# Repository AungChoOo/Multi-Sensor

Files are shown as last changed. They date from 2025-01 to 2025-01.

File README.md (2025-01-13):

<h1>Multi-Sensor</h1>

<h2>13 in 1 multi-sensor breadboard compatible module.</h2>

- IMU sensor([BMI088](https://www.bosch-sensortec.com/products/motion-sensors/imus/bmi088/))
- Magnetometer([BMM150](https://www.bosch-sensortec.com/products/motion-sensors/magnetometers/bmm150/))
- Gas Sensors([BME680](https://www.bosch-sensortec.com/products/environmental-sensors/gas-sensors/bme680/))

<h2>Rendered Image</h2>
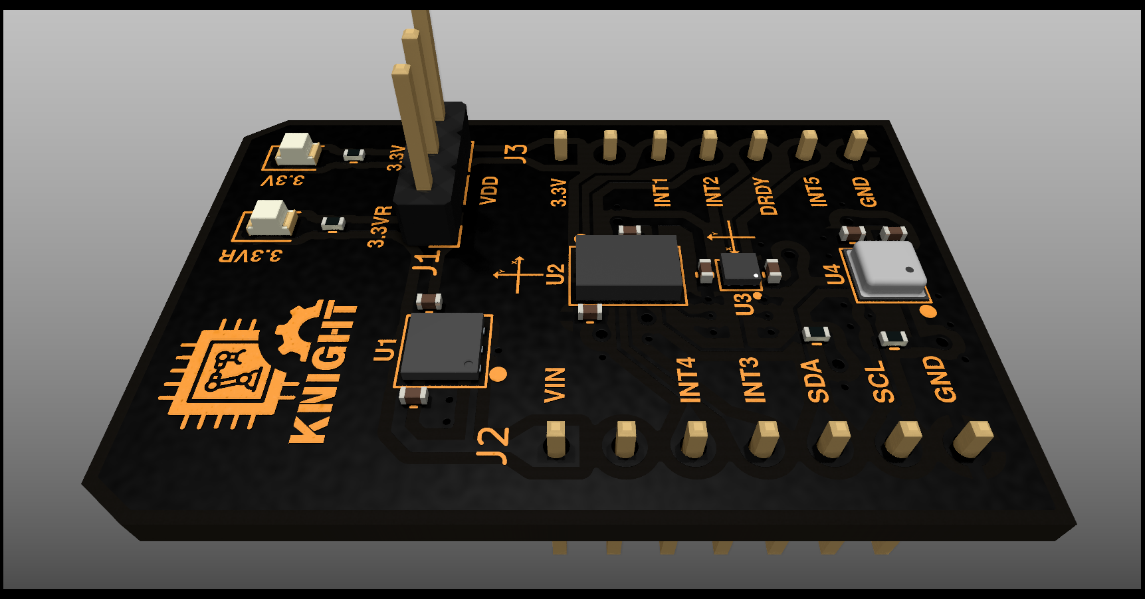
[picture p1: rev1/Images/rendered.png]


<h2>Front and Back Side</h2>
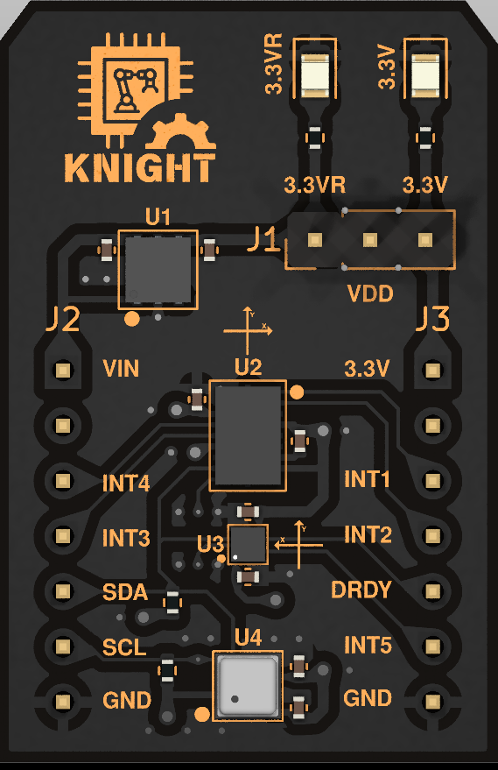
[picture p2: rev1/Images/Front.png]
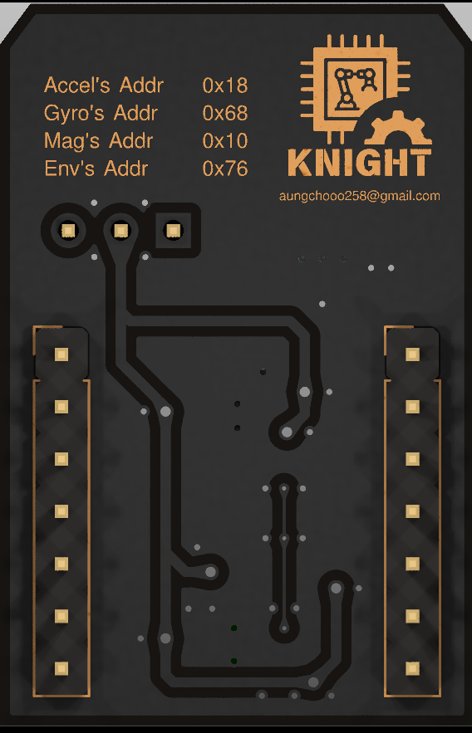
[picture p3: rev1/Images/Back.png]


## License
Resources of this repository are distributed under MIT License. 
See [LICENSE](./LICENSE).

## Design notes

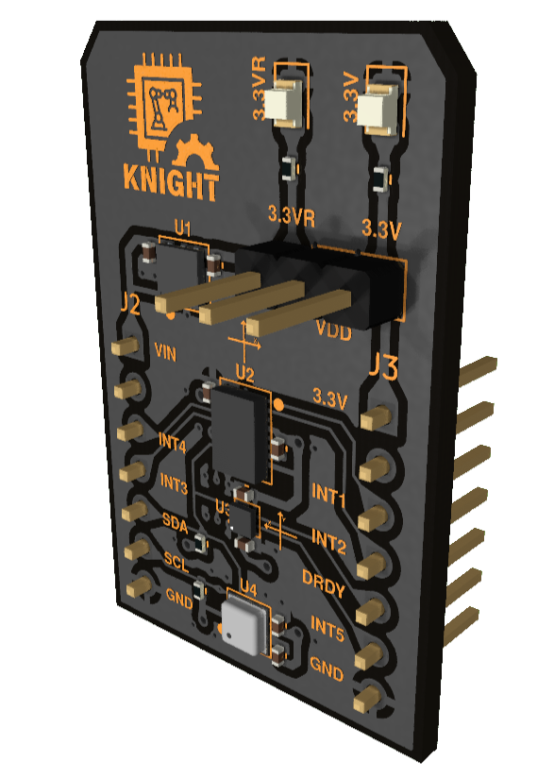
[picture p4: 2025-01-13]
rev1/Images/background_front.png

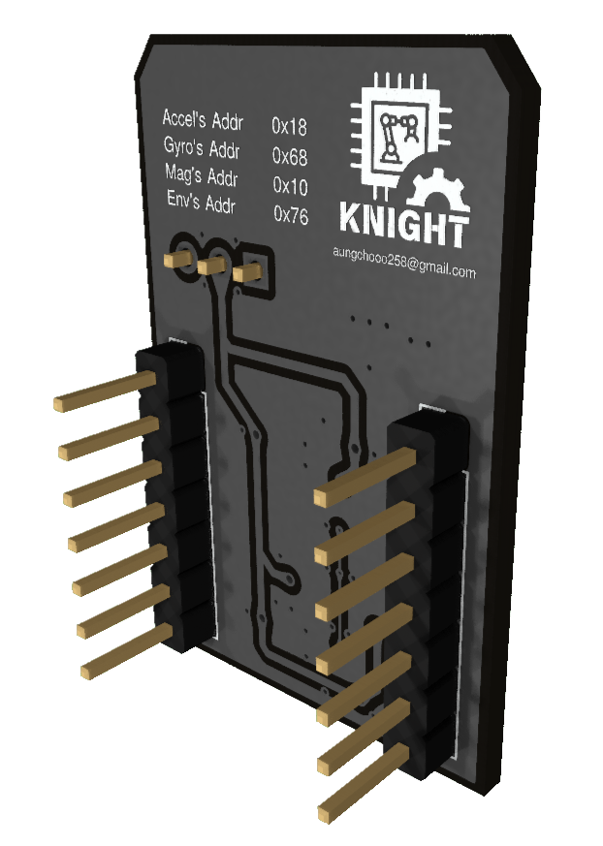
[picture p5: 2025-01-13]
rev1/Images/background_back.png

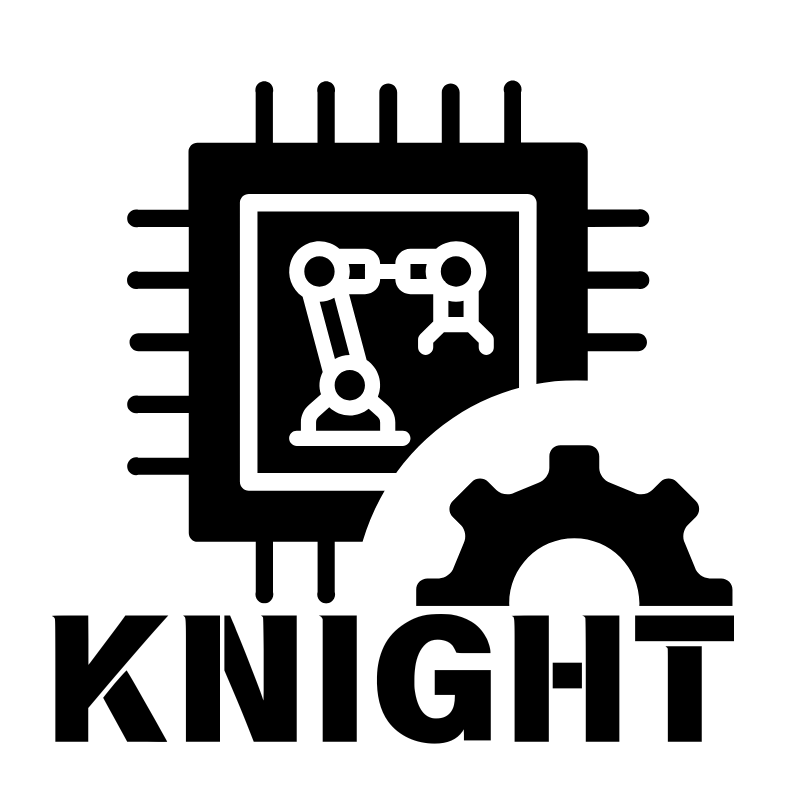
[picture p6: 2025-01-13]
rev1/Images/Knight.png

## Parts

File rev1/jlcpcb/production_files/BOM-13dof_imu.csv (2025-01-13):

Comment | Designator | Footprint | LCSC | Quantity
1kR | R1,R2 | R_0402_1005Metric | C11702 | 2
BME680 | U4 | BME680 | C125972 | 1
100nF | C3,C4,C5,C6,C7,C8 | C_0402_1005Metric | C1525 | 6
BMM150 | U3 | BMM150 | C171681 | 1
NCP708 | U1 | NCP708 | C183178 | 1
BMI088 | U2 | BMI088 | C194919 | 1
LED | D1,D2 | LED_0805_2012 | C2297 | 2
4u7F | C1,C2 | C_0402_1005Metric | C23733 | 2
4k7R | R4 | R_0402_1005Metric | C25900 | 1
Vbus | J1 | PinHeader_1x03_P2.54mm_Vertical | C6332196 | 1
Right | J3 | PinHeader_1x07_P2.54mm_Vertical |  | 1
Left | J2 | PinHeader_1x07_P2.54mm_Vertical |  | 1

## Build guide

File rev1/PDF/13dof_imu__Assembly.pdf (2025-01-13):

# Multi Sensor

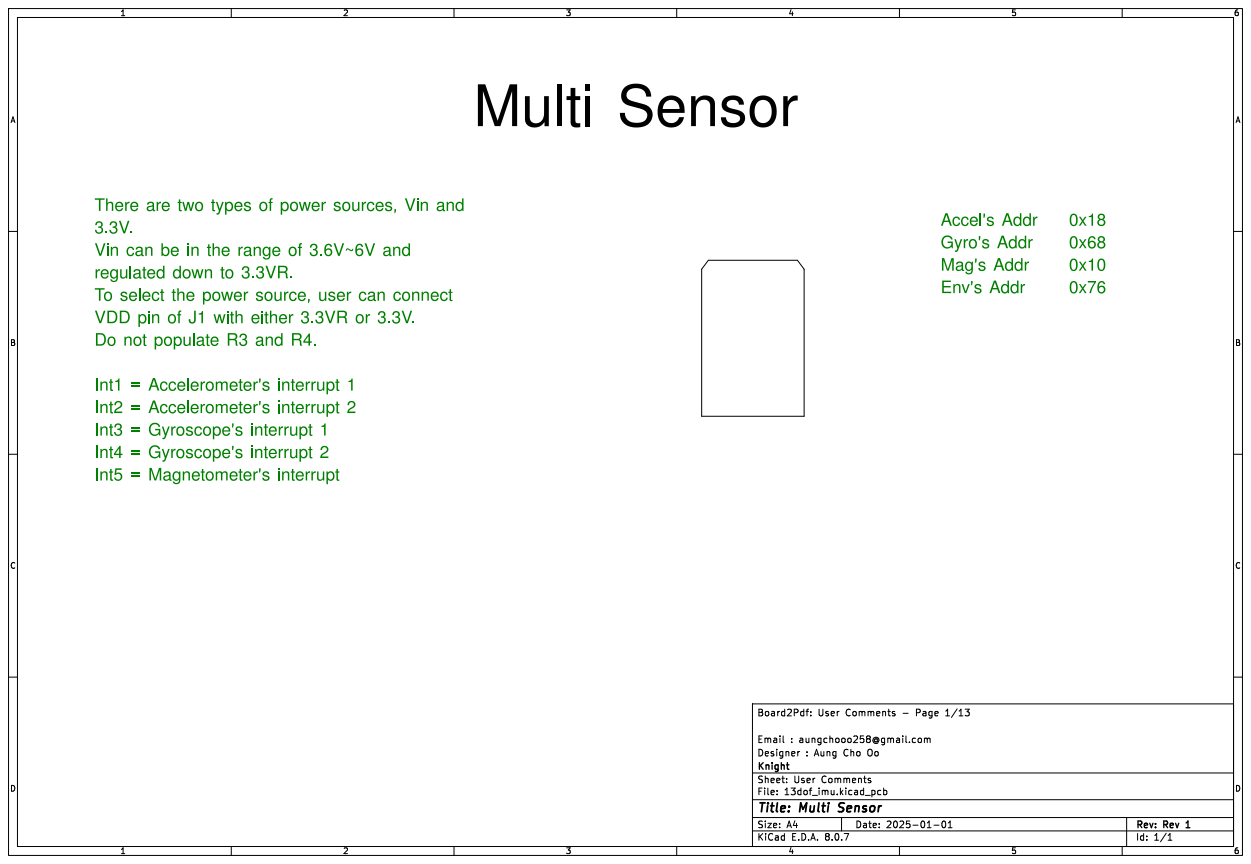
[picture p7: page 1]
Accel'sAddr 0x18 Gyro'sAddr 0x68 Mag's Addr 0x10 Env's Addr 0x76; Int1 = Accelerometer'sinterrupt1 Int2 = Accelerometer'sinterrupt2 Int3 = Gyroscope'sinterrupt1 Int4 = Gyroscope'sinterrupt2 Int5 = Magnetometer'sinterrupt; D Date: 2025-01-01 KiCad; E.D.A. 8.0.7 Size: A4; Rev:; Rev; Board2Pdf:; User Comments -; Page

There are two types of power sources,Vin and
Vin can be in the range of 3.6V~6Vand
regulateddown to 3.3VR.
To select the power source,user can connect
VDD pin of J1 with either 3.3VR or 3.3V.
Do not populateR3 and R4.

Designer : Aung Cho Oo Email : aungchooo258@gmail.com

Id: 1/1 Title: Multi Sensor File: 13dof_imu.kicad_pcb Sheet: User Comments Knight

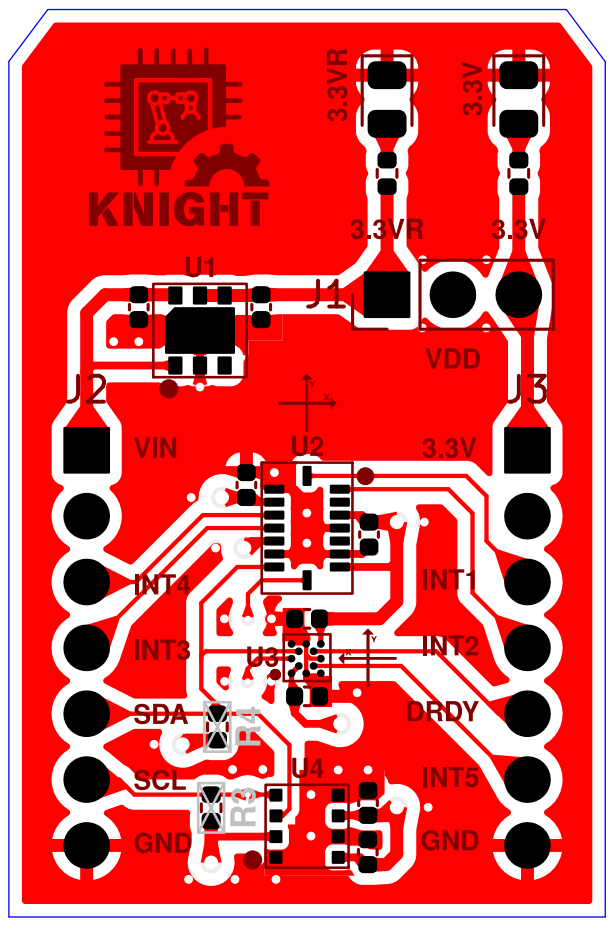
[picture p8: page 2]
DRDY; SCL; INT5 SDA; INT1; INT2 GND; VDD; VIN; GND; INT3; INT4; D Date: 2025-01-01 KiCad; E.D.A. 8.0.7 Size: A4; Rev:; Rev; Board2Pdf:; TOP -; Page 2/13

Designer : Aung Cho Oo Email : aungchooo258@gmail.com

Id: 1/1 Title: Multi Sensor File: 13dof_imu.kicad_pcb Sheet: TOP Knight

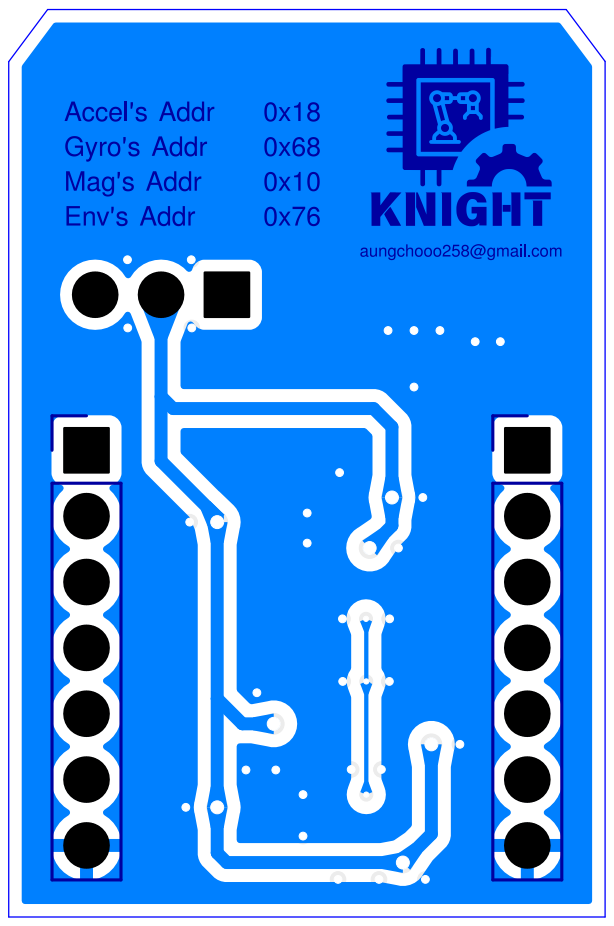
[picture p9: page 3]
aungchooo258@gmail.com Accel'sAddr 0x18 Gyro'sAddr 0x68 Mag's Addr 0x10 Env's Addr 0x76 1; D Date: 2025-01-01 KiCad; E.D.A. 8.0.7 Size: A4; Rev:; Rev; Board2Pdf:; BOT -; Page 3/13

Designer : Aung Cho Oo Email : aungchooo258@gmail.com

Id: 1/1 Title: Multi Sensor File: 13dof_imu.kicad_pcb Sheet: BOT Knight

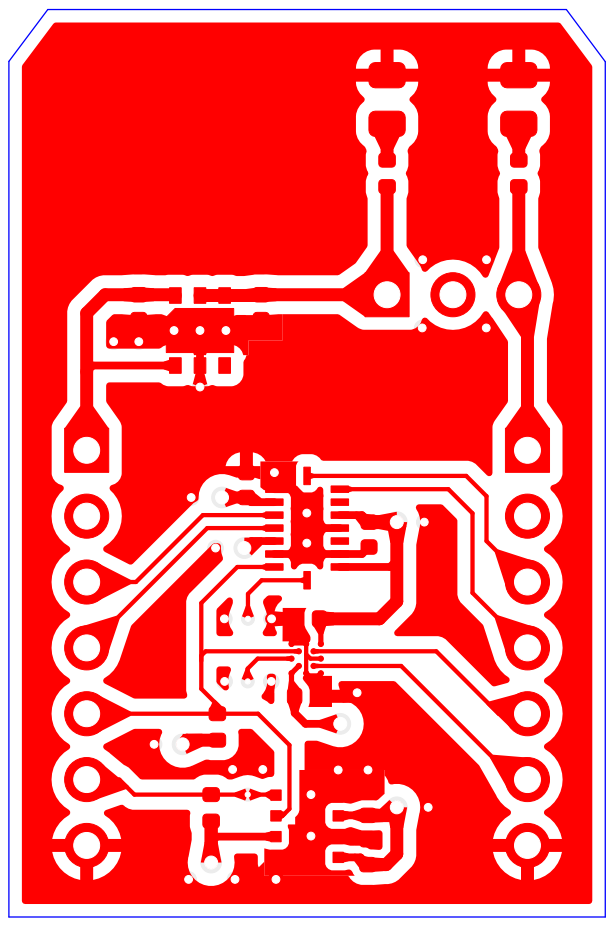
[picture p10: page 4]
D Date: 2025-01-01 KiCad; E.D.A. 8.0.7 Size: A4; Rev:; Rev; Board2Pdf:; Front Copper -; Page 4/13

Designer : Aung Cho Oo Email : aungchooo258@gmail.com

Knight
Id: 1/1 Title: Multi Sensor File: 13dof_imu.kicad_pcb Sheet: Front Copper

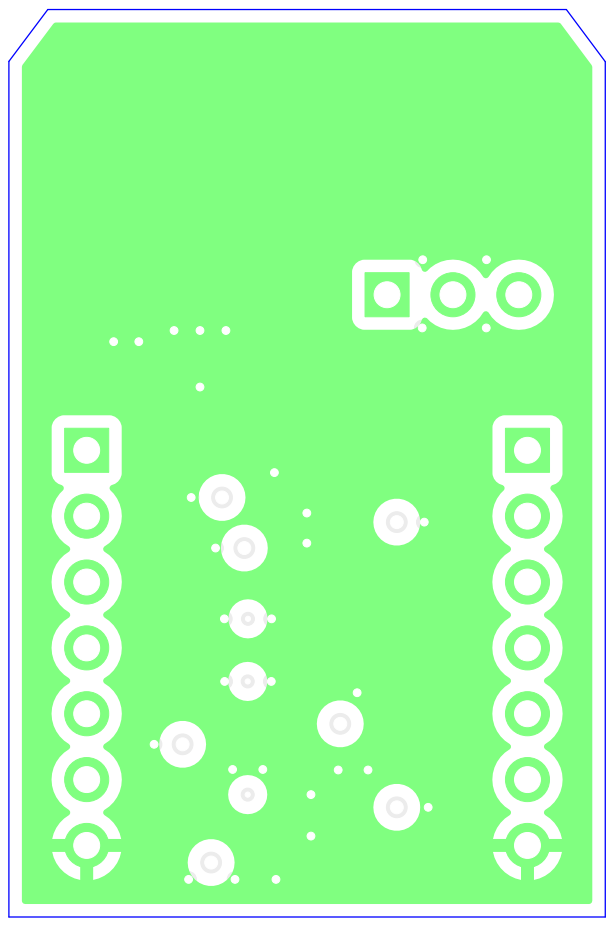
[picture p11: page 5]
D Date: 2025-01-01 KiCad; E.D.A. 8.0.7 Size: A4; Rev:; Rev; Board2Pdf:; Copper -; Page 5/13

Designer : Aung Cho Oo Email : aungchooo258@gmail.com

Knight
Id: 1/1 Title: Multi Sensor File: 13dof_imu.kicad_pcb Sheet: L1 Copper

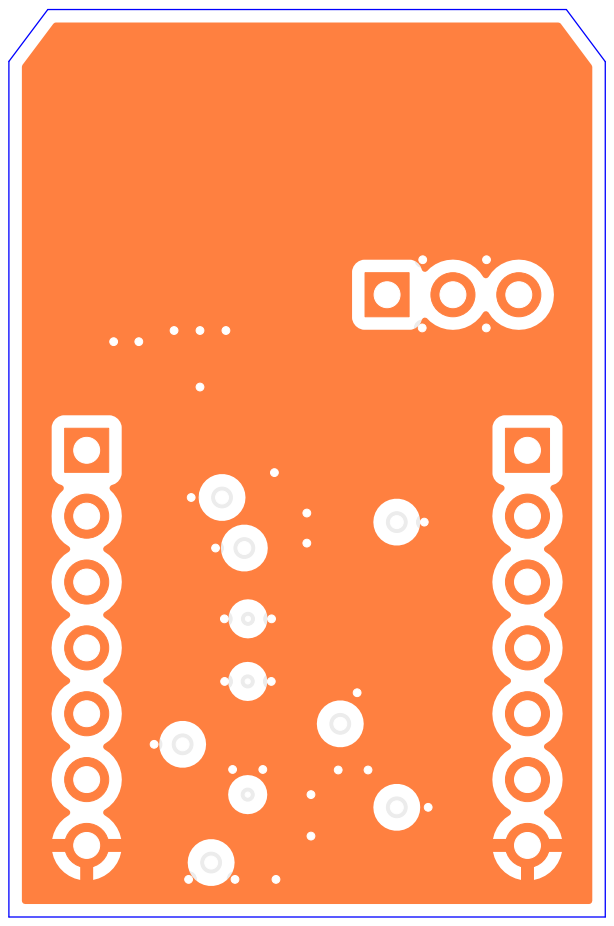
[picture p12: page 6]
D Date: 2025-01-01 KiCad; E.D.A. 8.0.7 Size: A4; Rev:; Rev; Board2Pdf:; L2 Copper -; Page 6/13

Designer : Aung Cho Oo Email : aungchooo258@gmail.com

Knight
Id: 1/1 Title: Multi Sensor File: 13dof_imu.kicad_pcb Sheet: L2 Copper

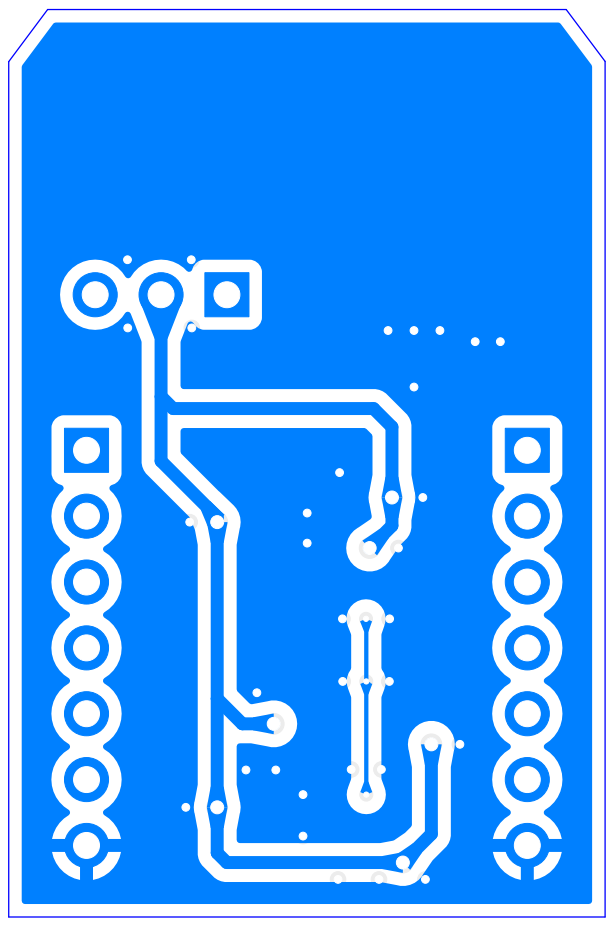
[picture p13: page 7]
D Date: 2025-01-01 KiCad; E.D.A. 8.0.7 Size: A4; Rev:; Rev; Board2Pdf:; Back; Copper -; Page 7/13

Designer : Aung Cho Oo Email : aungchooo258@gmail.com

Knight
Id: 1/1 Title: Multi Sensor File: 13dof_imu.kicad_pcb Sheet: Back Copper

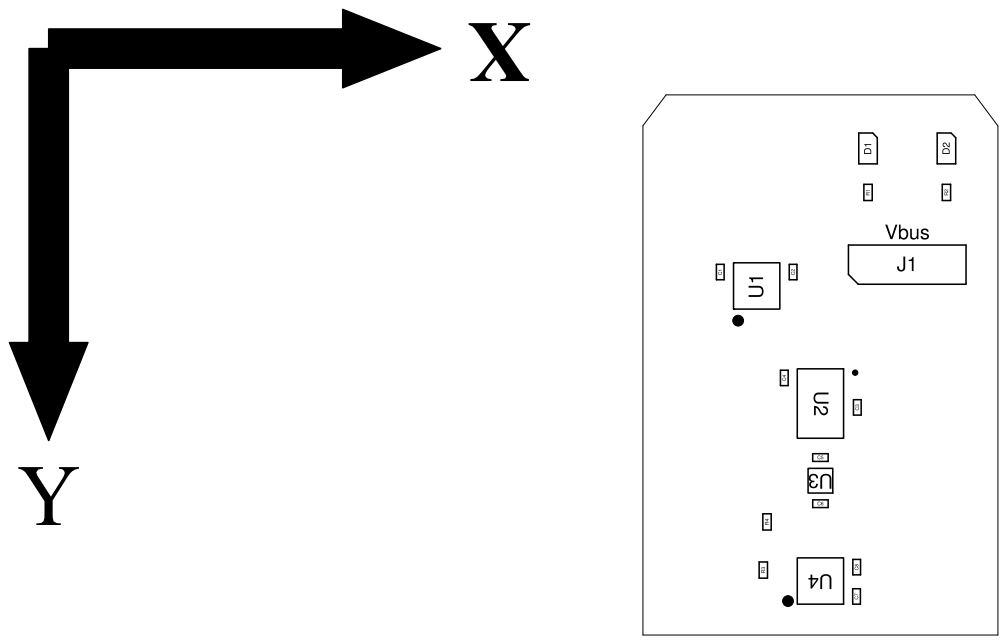
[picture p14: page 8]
D Date: 2025-01-01 KiCad; E.D.A. 8.0.7 Size: A4; Rev:; Rev; Id: 1/1 Title: Multi Sensor File: 13dof_imu.kicad_pcb Sheet: TOP; FAB Knight; Board2Pdf:; TOP; FAB -; Page 8/13

Designer : Aung Cho Oo Email : aungchooo258@gmail.com

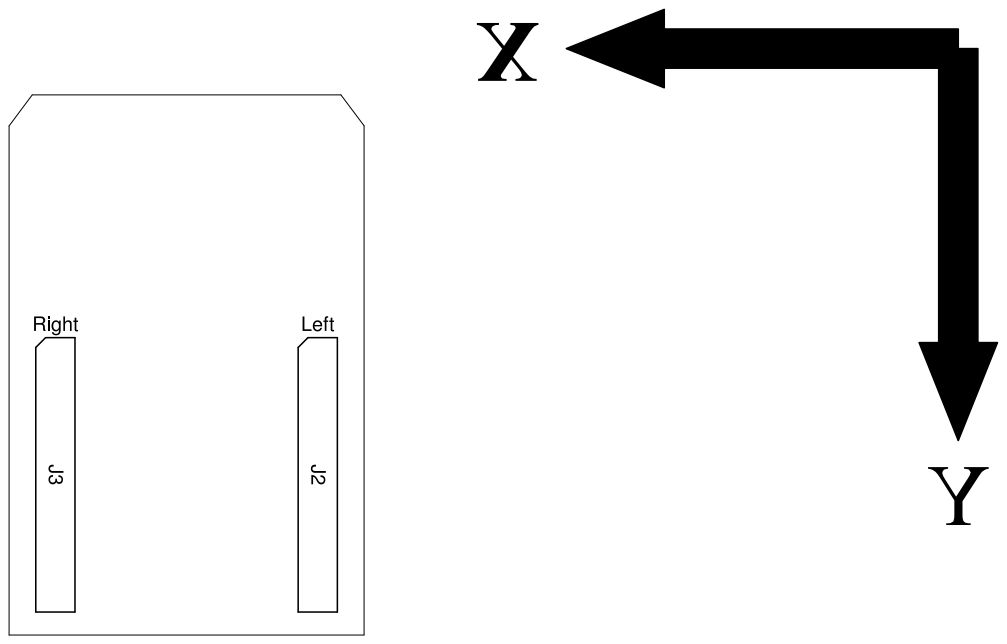
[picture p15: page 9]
Right J3; Left J2 1; D Date: 2025-01-01 KiCad; E.D.A. 8.0.7 Size: A4; Rev:; Rev; Id: 1/1 Title: Multi Sensor File: 13dof_imu.kicad_pcb Sheet: BOT; FAB Knight; Board2Pdf:; BOT; FAB -; Page 9/13

Designer : Aung Cho Oo Email : aungchooo258@gmail.com

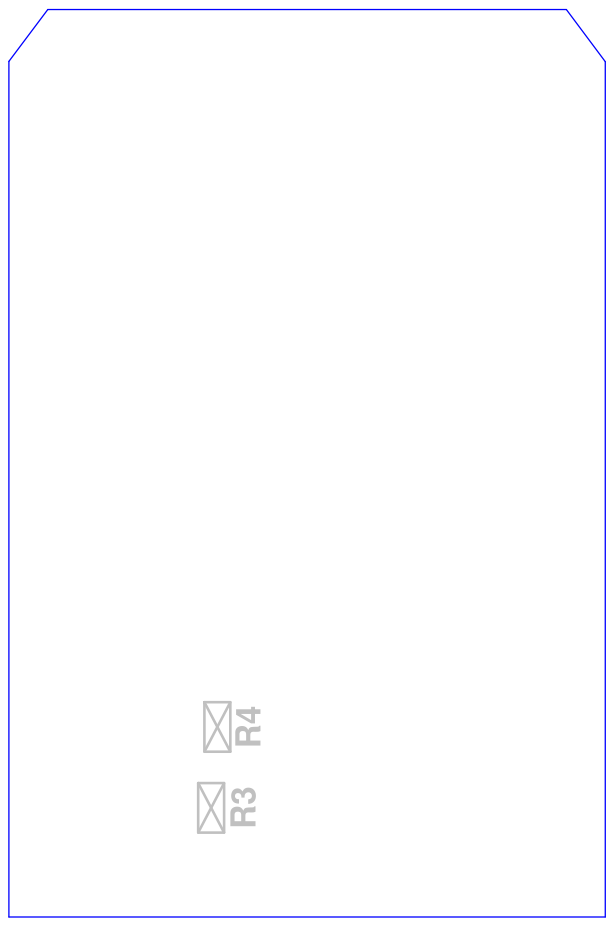
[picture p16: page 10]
D Date: 2025-01-01 KiCad; E.D.A. 8.0.7 Size: A4; Rev:; Rev; Id: 1/1 Title: Multi Sensor File: 13dof_imu.kicad_pcb Sheet: TOP; DNP Knight; Board2Pdf:; TOP; DNP -; Page

Designer : Aung Cho Oo Email : aungchooo258@gmail.com

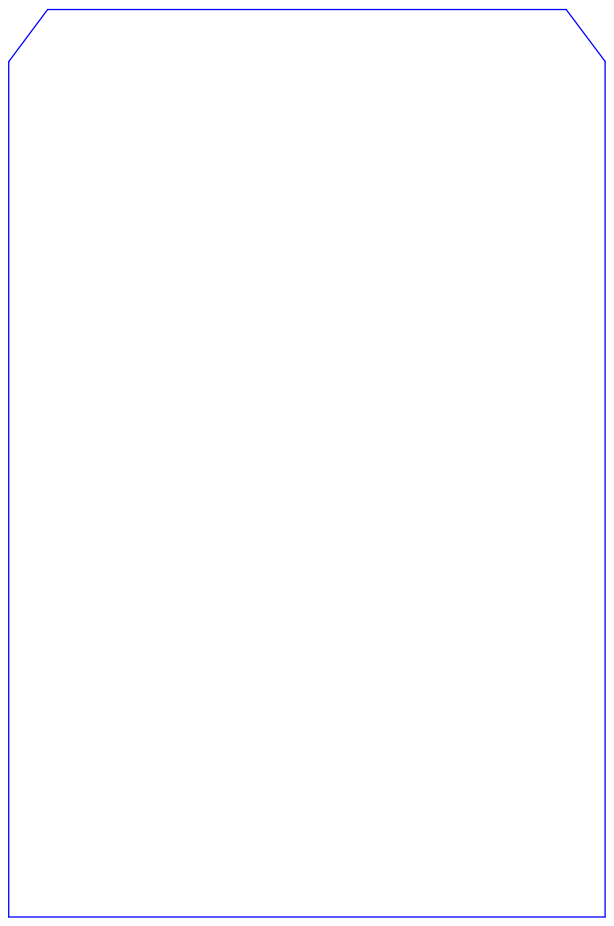
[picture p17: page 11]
D Date: 2025-01-01 KiCad; E.D.A. 8.0.7 Size: A4; Rev:; Rev; Id: 1/1 Title: Multi Sensor File: 13dof_imu.kicad_pcb Sheet: BOT; DNP Knight; Board2Pdf:; BOT; DNP -; Page

Designer : Aung Cho Oo Email : aungchooo258@gmail.com

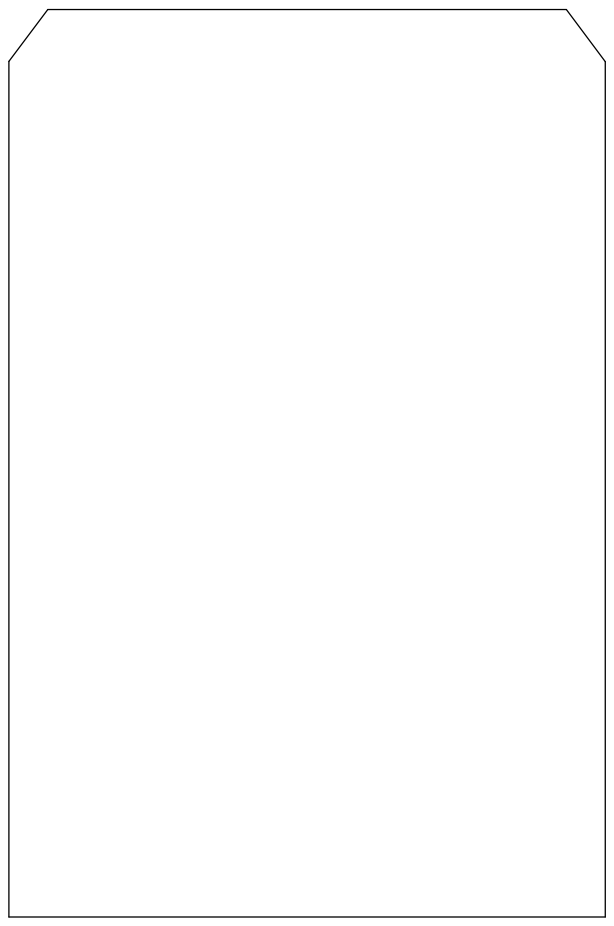
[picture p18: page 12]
D Date: 2025-01-01 KiCad; E.D.A. 8.0.7 Size: A4; Rev:; Rev; Board2Pdf:; Stackup; Page

Designer : Aung Cho Oo Email : aungchooo258@gmail.com

Knight
Id: 1/1 Title: Multi Sensor File: 13dof_imu.kicad_pcb Sheet: Stackup

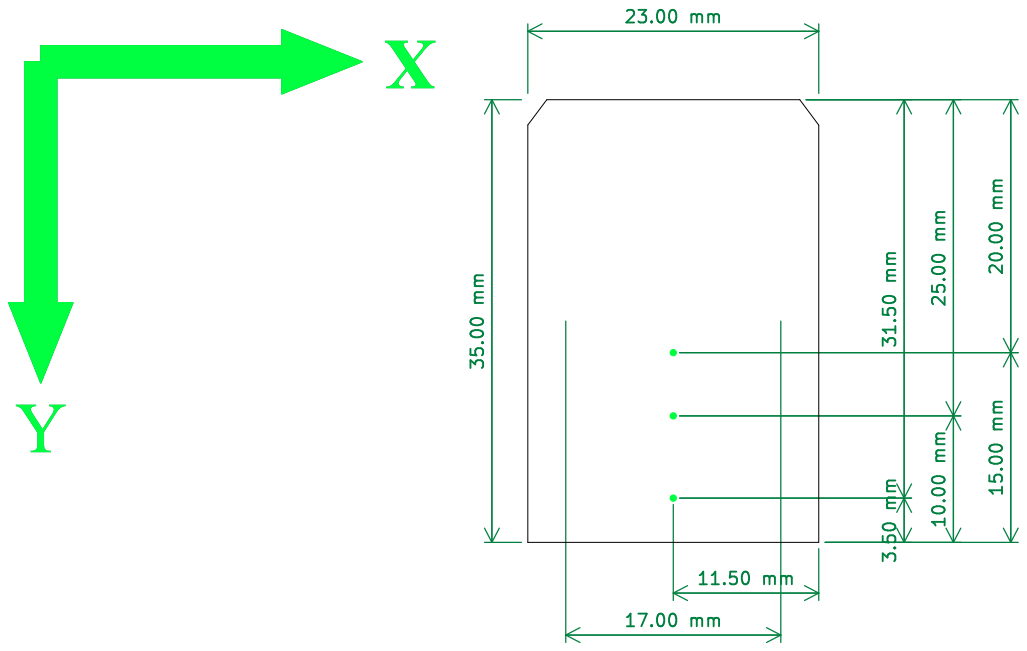
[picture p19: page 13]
6 ABCD; ABCD Date: 2025-01-01 KiCad; E.D.A. 8.0.7 Size: A4; Rev:; Rev; Id: 1/1 Title: Multi Sensor File: 13dof_imu.kicad_pcb Sheet: Mechanical; Info Knight; Board2Pdf:; Mechanical; Info -; Page

Designer : Aung Cho Oo Email : aungchooo258@gmail.com

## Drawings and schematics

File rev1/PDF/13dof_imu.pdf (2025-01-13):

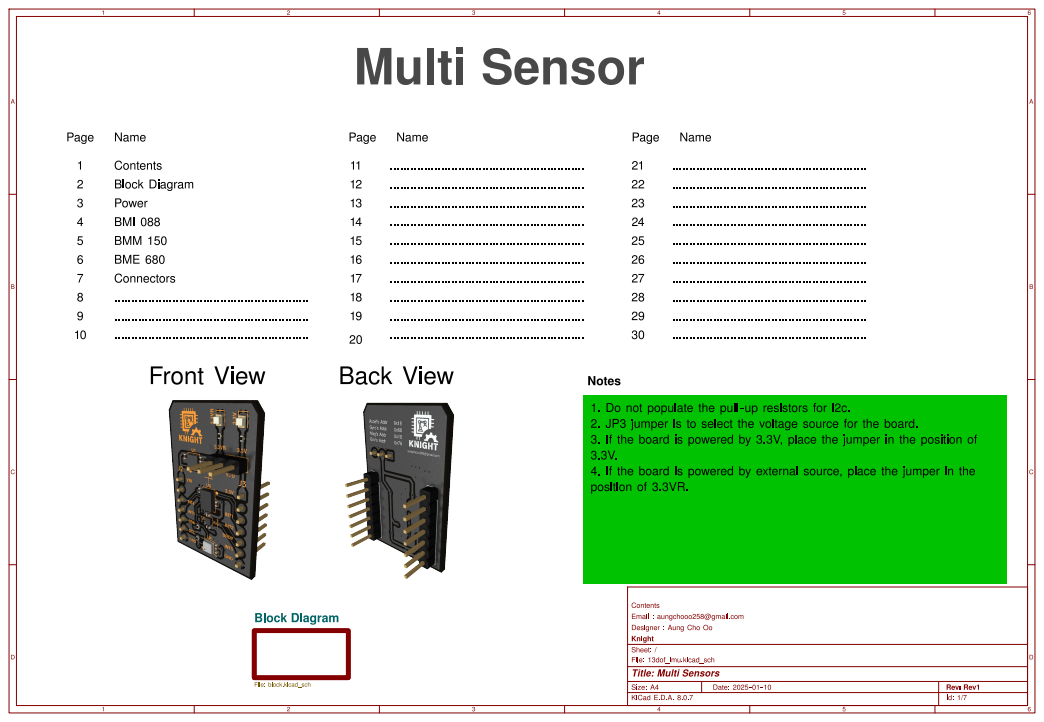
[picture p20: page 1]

1. Do not populatethe pull-up resistorsfor i2c.
2. JP3 jumperis to select the voltagesourcefor the board.
3. If the board is poweredby 3.3V,place the jumperin the positionof
4. If the board is poweredby externalsource,place the jumperin the
positionof 3.3VR.

Designer: Aung Cho Oo Email : aungchooo258@gmail.com

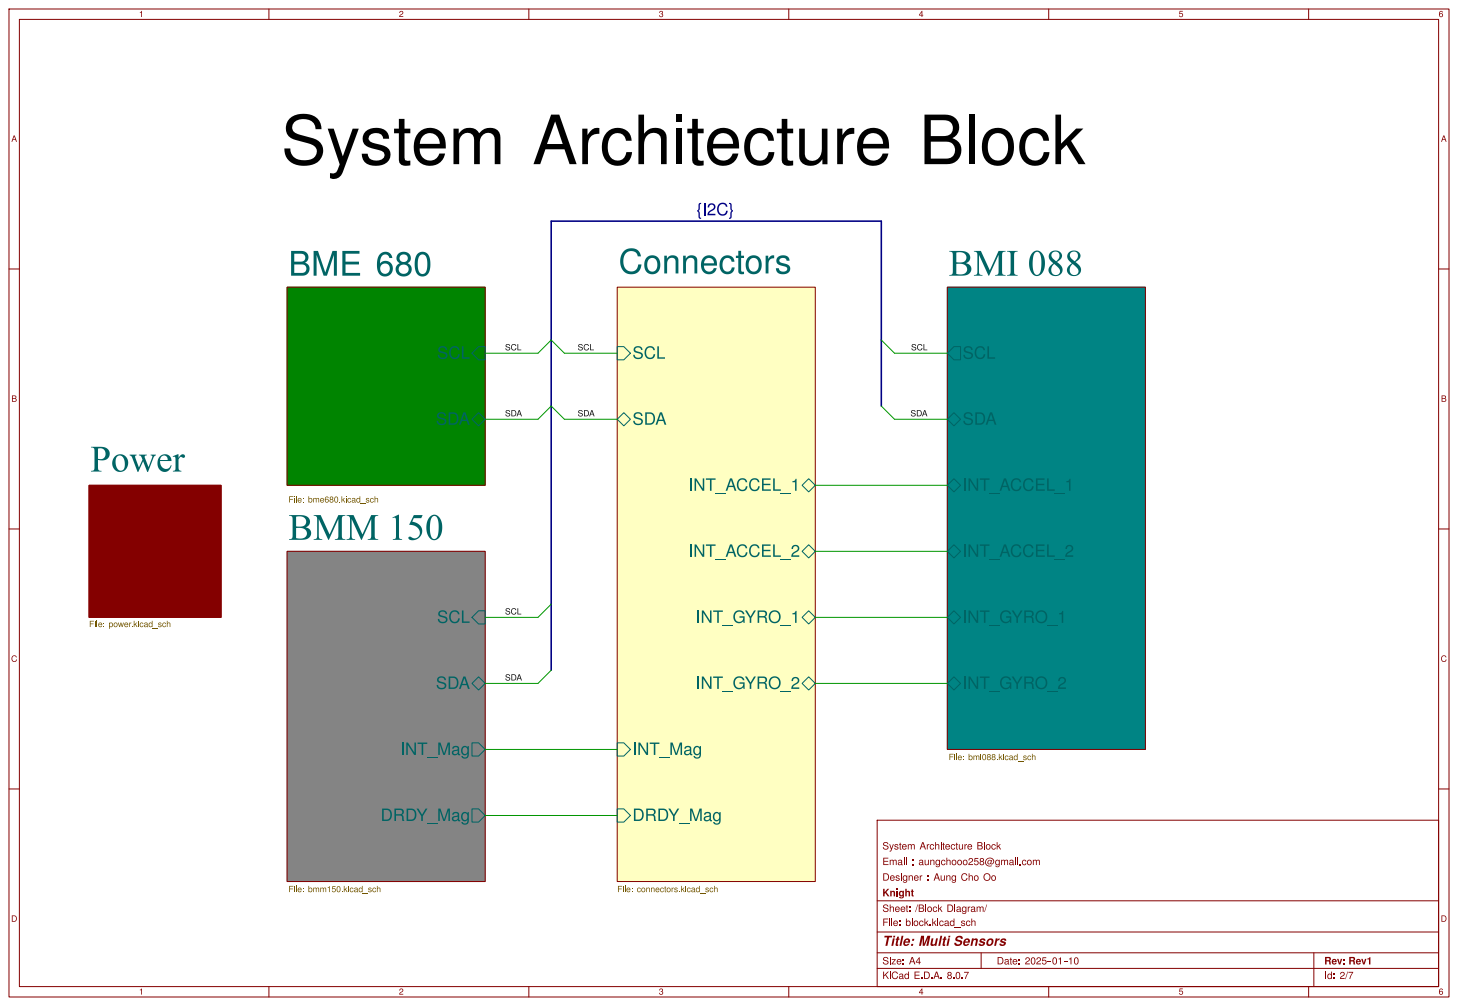
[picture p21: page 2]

Designer: Aung Cho Oo Email : aungchooo258@gmail.com

Knight
File: block.kicad_sch Sheet:/Block Diagram/
Id: 2/7 Title:MultiSensors

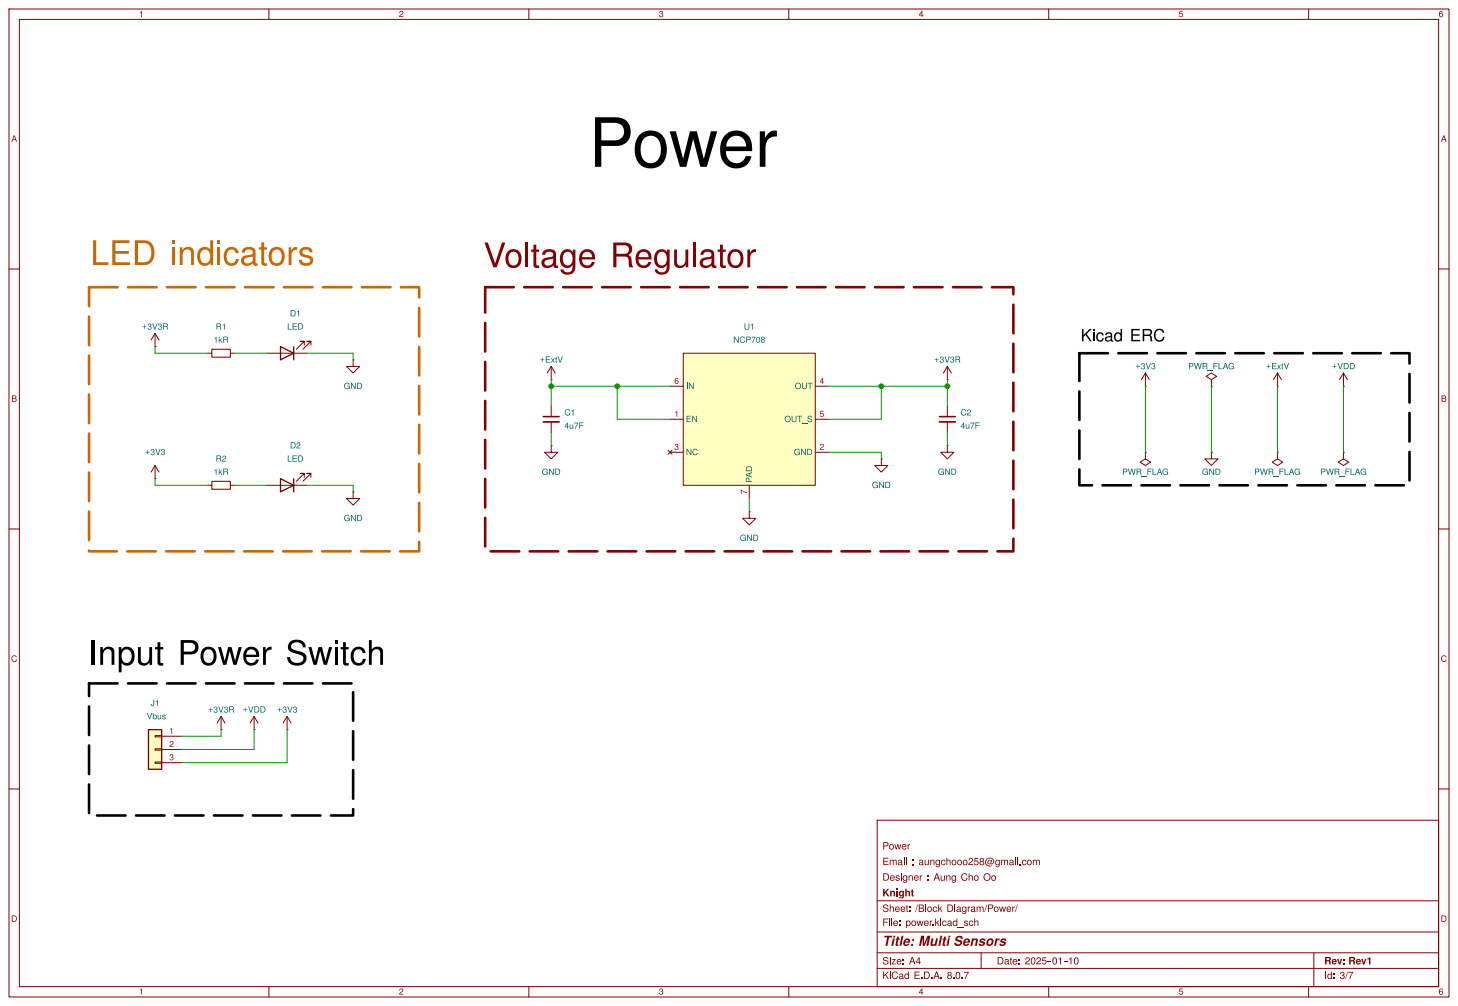
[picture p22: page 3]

Designer: Aung Cho Oo Email : aungchooo258@gmail.com

Knight
File: power.kicad_sch Sheet:/Block Diagram/Power/
Id: 3/7 Title:MultiSensors

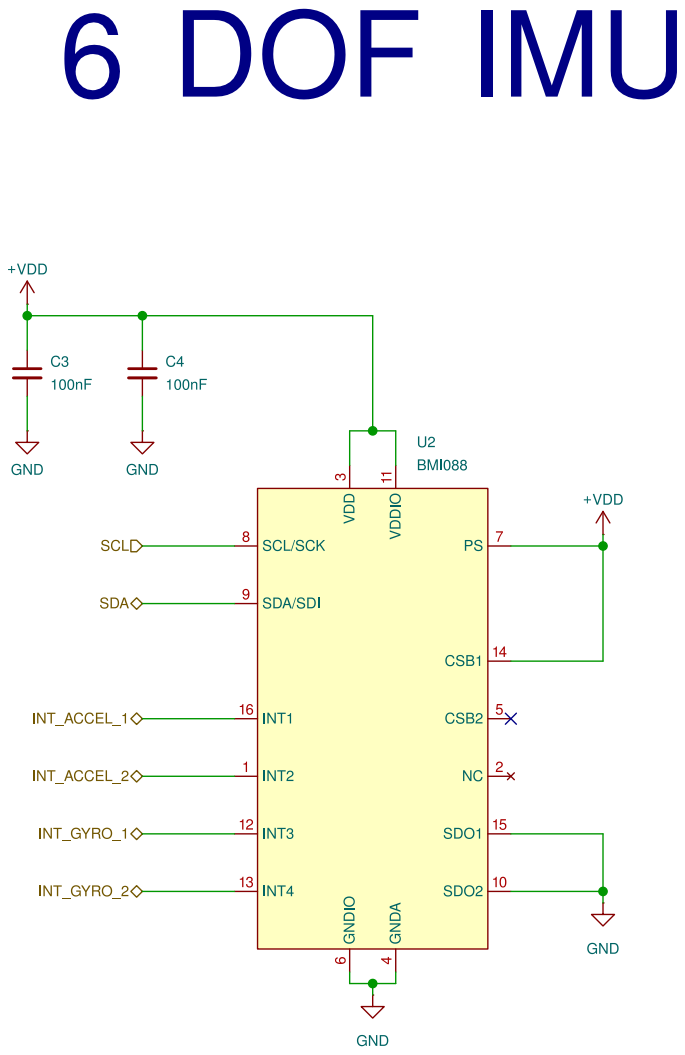
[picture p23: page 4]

INT_GYRO_1 SCL SDA 6 DOF IMU

3 CSB2 5 SCL/SCK 8 SDA/SDI 9 U2BMI088 C3

Designer: Aung Cho Oo Email : aungchooo258@gmail.com

File: bmi088.kicad_sch Sheet:/Block Diagram/BMI088/ Knight

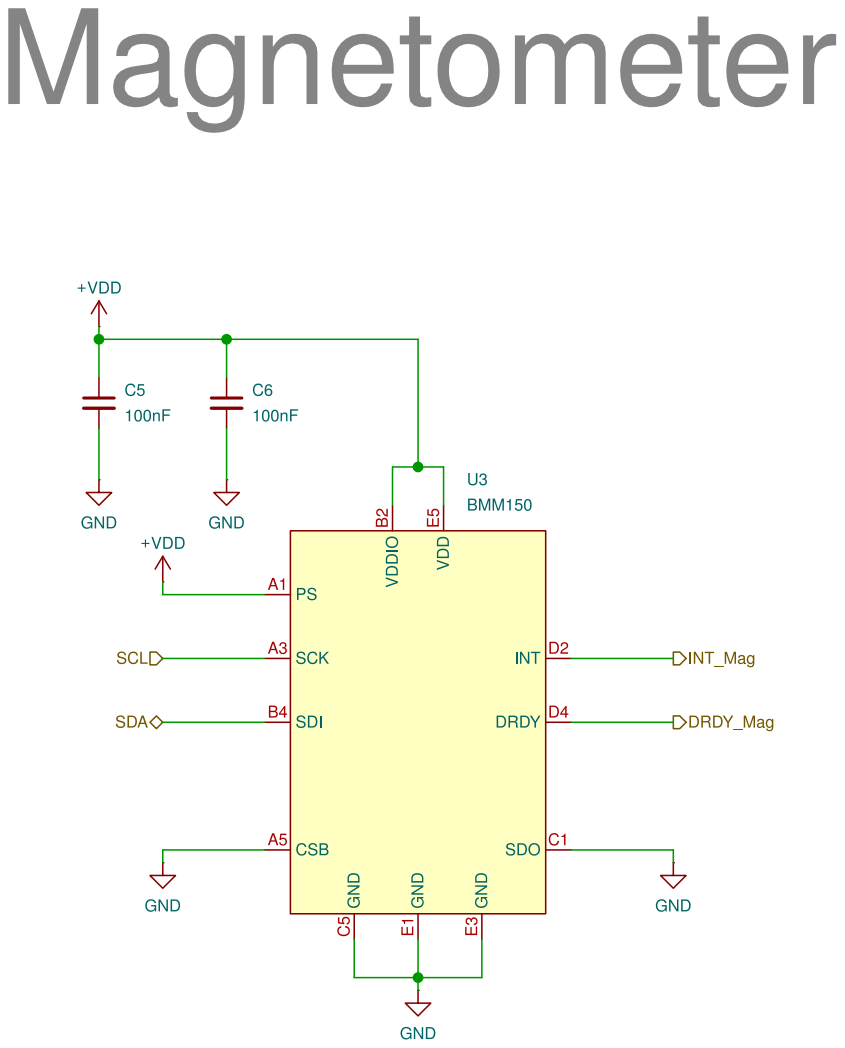
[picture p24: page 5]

Designer: Aung Cho Oo Email : aungchooo258@gmail.com

File: bmm150.kicad_sch Sheet:/Block Diagram/BMM150/ Knight

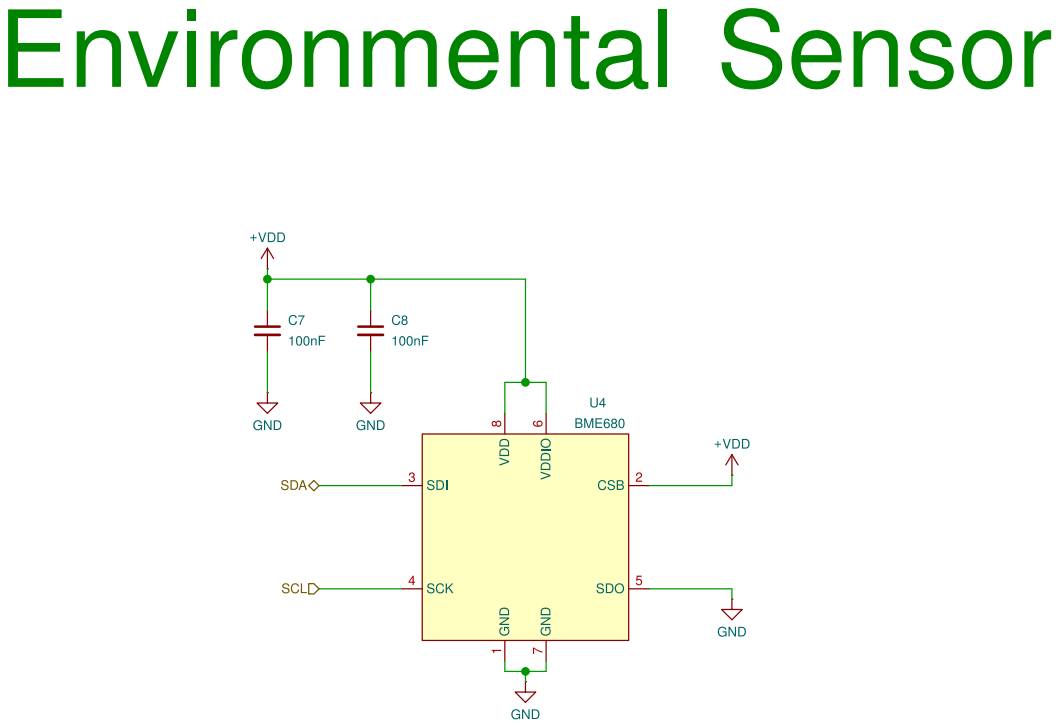
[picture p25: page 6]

1 CSB 2 SDI 3 SCK 4 VDDIO

Designer: Aung Cho Oo Email : aungchooo258@gmail.com

File: bme680.kicad_sch Sheet:/Block Diagram/BME680/ Knight

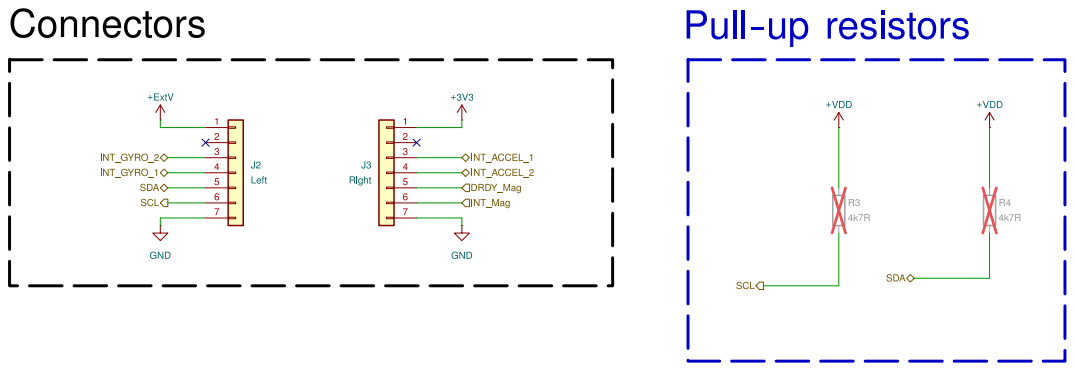
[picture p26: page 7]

Connectors
Designer: Aung Cho Oo Email : aungchooo258@gmail.com

Knight
File: connectors.kicad_sch Sheet:/Block Diagram/Connectors/
Id: 7/7 Title:MultiSensors

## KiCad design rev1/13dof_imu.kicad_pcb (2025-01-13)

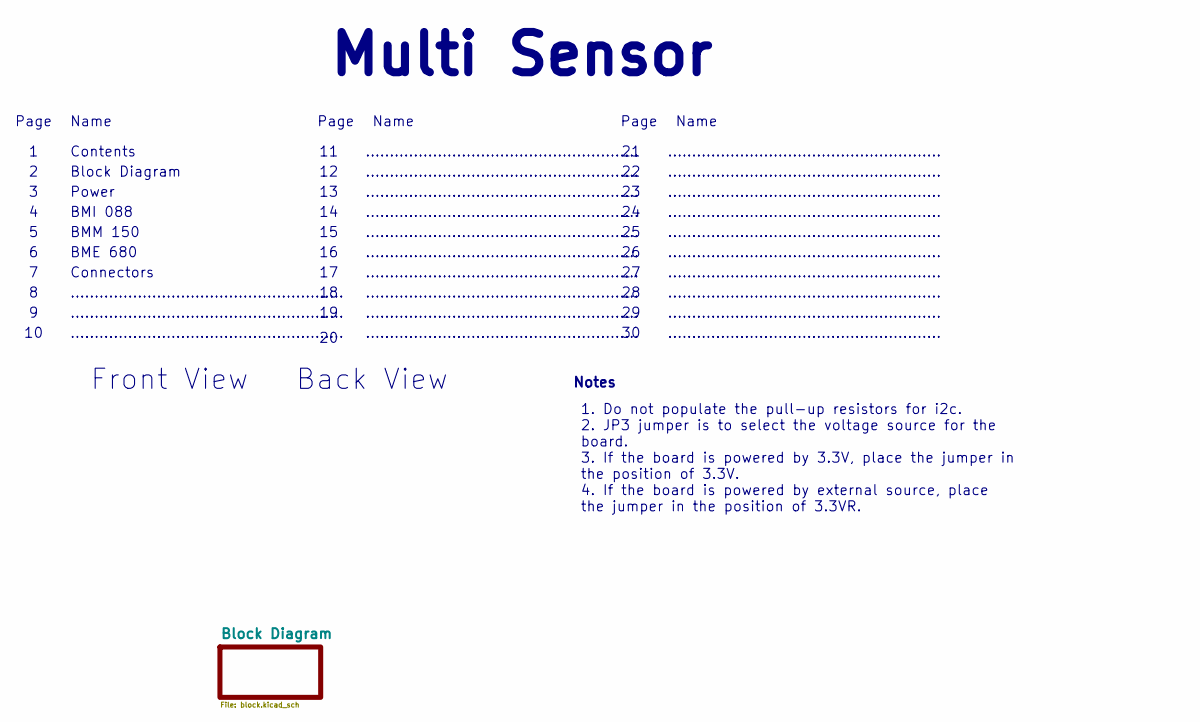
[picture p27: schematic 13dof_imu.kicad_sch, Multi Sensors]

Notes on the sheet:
1. Do not populate the pull-up resistors for i2c. 2. JP3 jumper is to select the voltage source for the board. 3. If the board is powered by 3.3V, place the jumper in the position of 3.3V. 4. If the board is powered by external source, place the jumper in the position of 3.3VR.
.........................................................
Front View
Notes
Page
Power
Name
Block Diagram
Multi Sensor
Connectors
BMM 150
BME 680
Back View
BMI 088
Contents

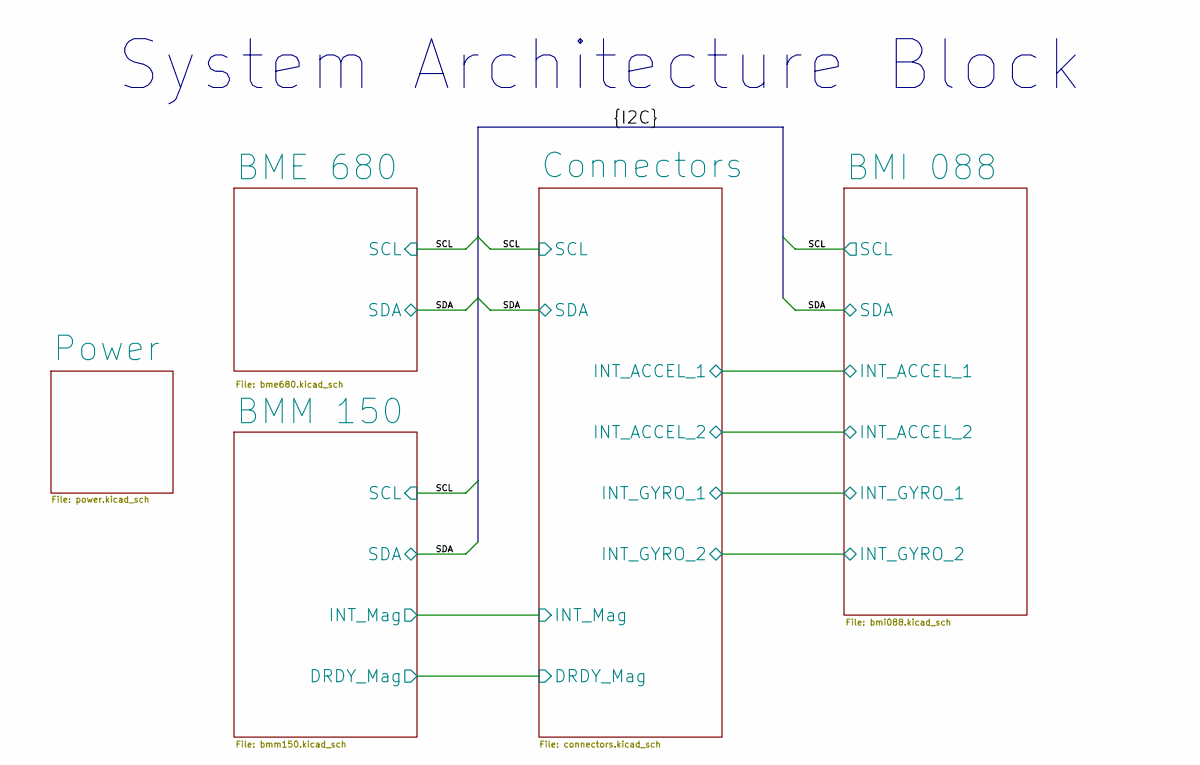
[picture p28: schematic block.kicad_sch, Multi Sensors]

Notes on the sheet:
System Architecture Block

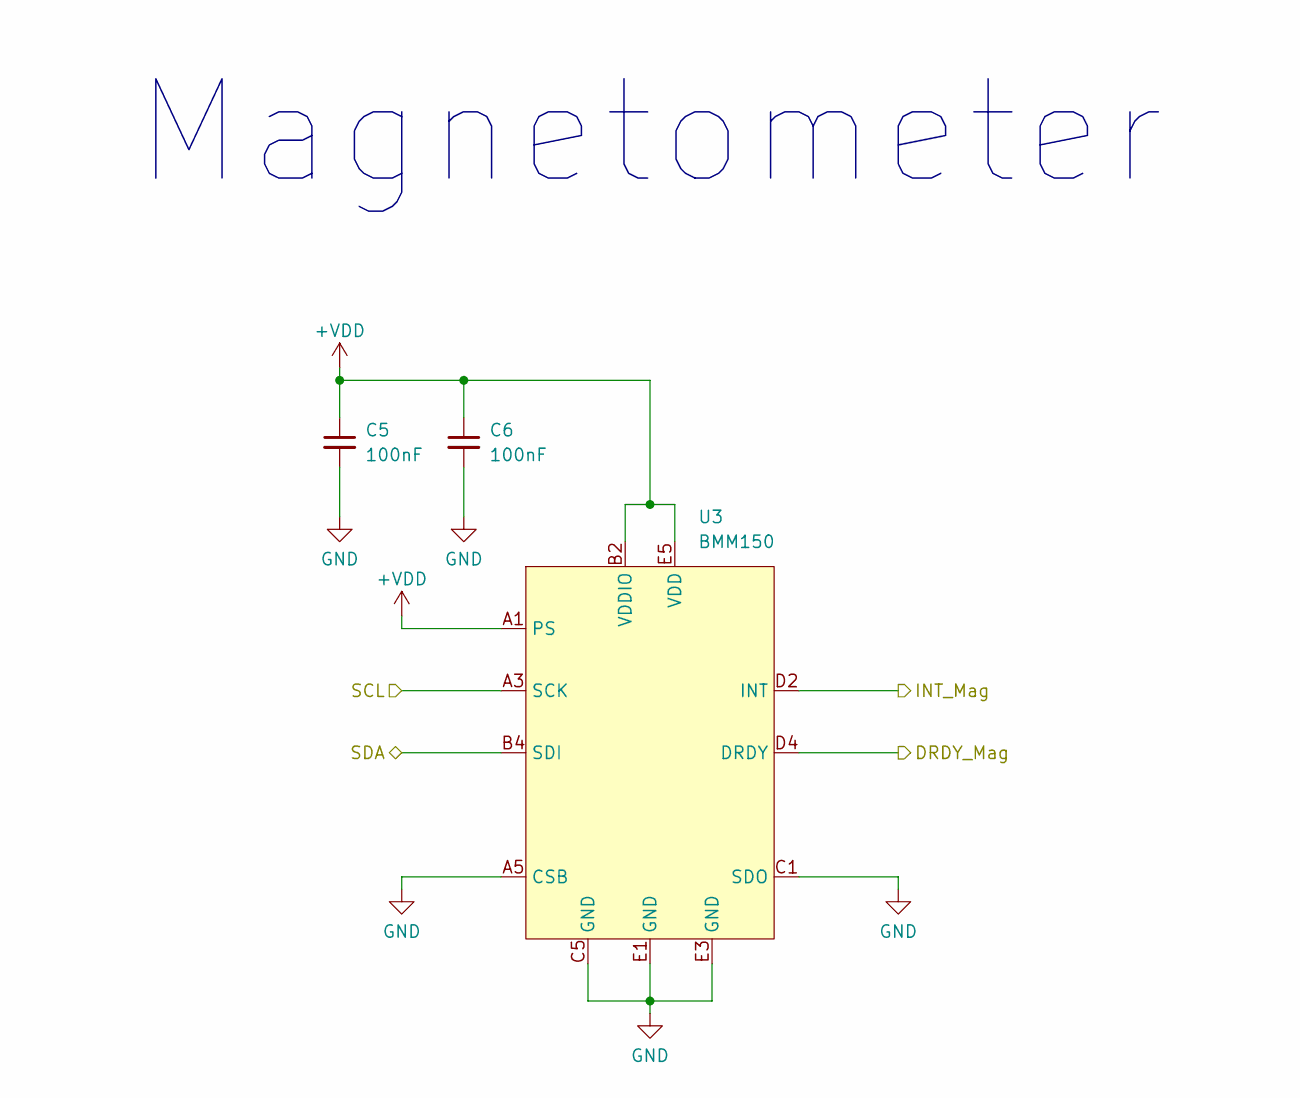
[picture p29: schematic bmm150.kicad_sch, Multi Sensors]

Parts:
C5, C6: 100nF; C_0402_1005Metric
U3: BMM150

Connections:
+VDD: C5.1, C6.1, U3.A1 (PS), U3.B2 (VDDIO), U3.E5 (VDD); also elsewhere on the board
/Block Diagram/BMM 150/DRDY_Mag: U3.D4 (DRDY); also elsewhere on the board
/Block Diagram/BMM 150/INT_Mag: U3.D2 (INT); also elsewhere on the board
/Block Diagram/SCL: U3.A3 (SCK); also elsewhere on the board
/Block Diagram/SDA: U3.B4 (SDI); also elsewhere on the board
GND: C5.2, C6.2, U3.A5 (CSB), U3.C1 (SDO), U3.C5 (GND), U3.E1 (GND), U3.E3 (GND); also elsewhere on the board

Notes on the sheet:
Magnetometer

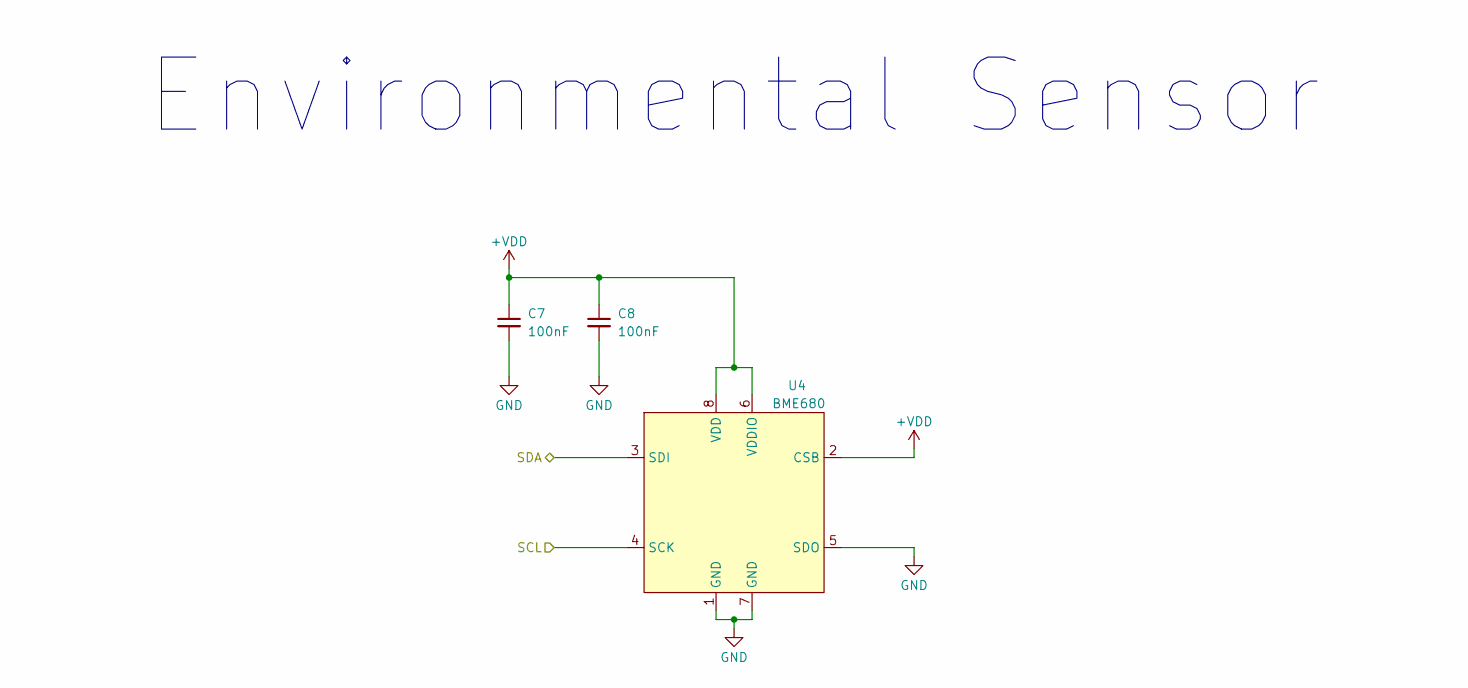
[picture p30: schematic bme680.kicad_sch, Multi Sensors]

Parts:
C7, C8: 100nF; C_0402_1005Metric
U4: BME680

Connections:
+VDD: C7.1, C8.1, U4.2 (CSB), U4.6 (VDDIO), U4.8 (VDD); also elsewhere on the board
/Block Diagram/SCL: U4.4 (SCK); also elsewhere on the board
/Block Diagram/SDA: U4.3 (SDI); also elsewhere on the board
GND: C7.2, C8.2, U4.1 (GND), U4.5 (SDO), U4.7 (GND); also elsewhere on the board

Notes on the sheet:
Environmental Sensor

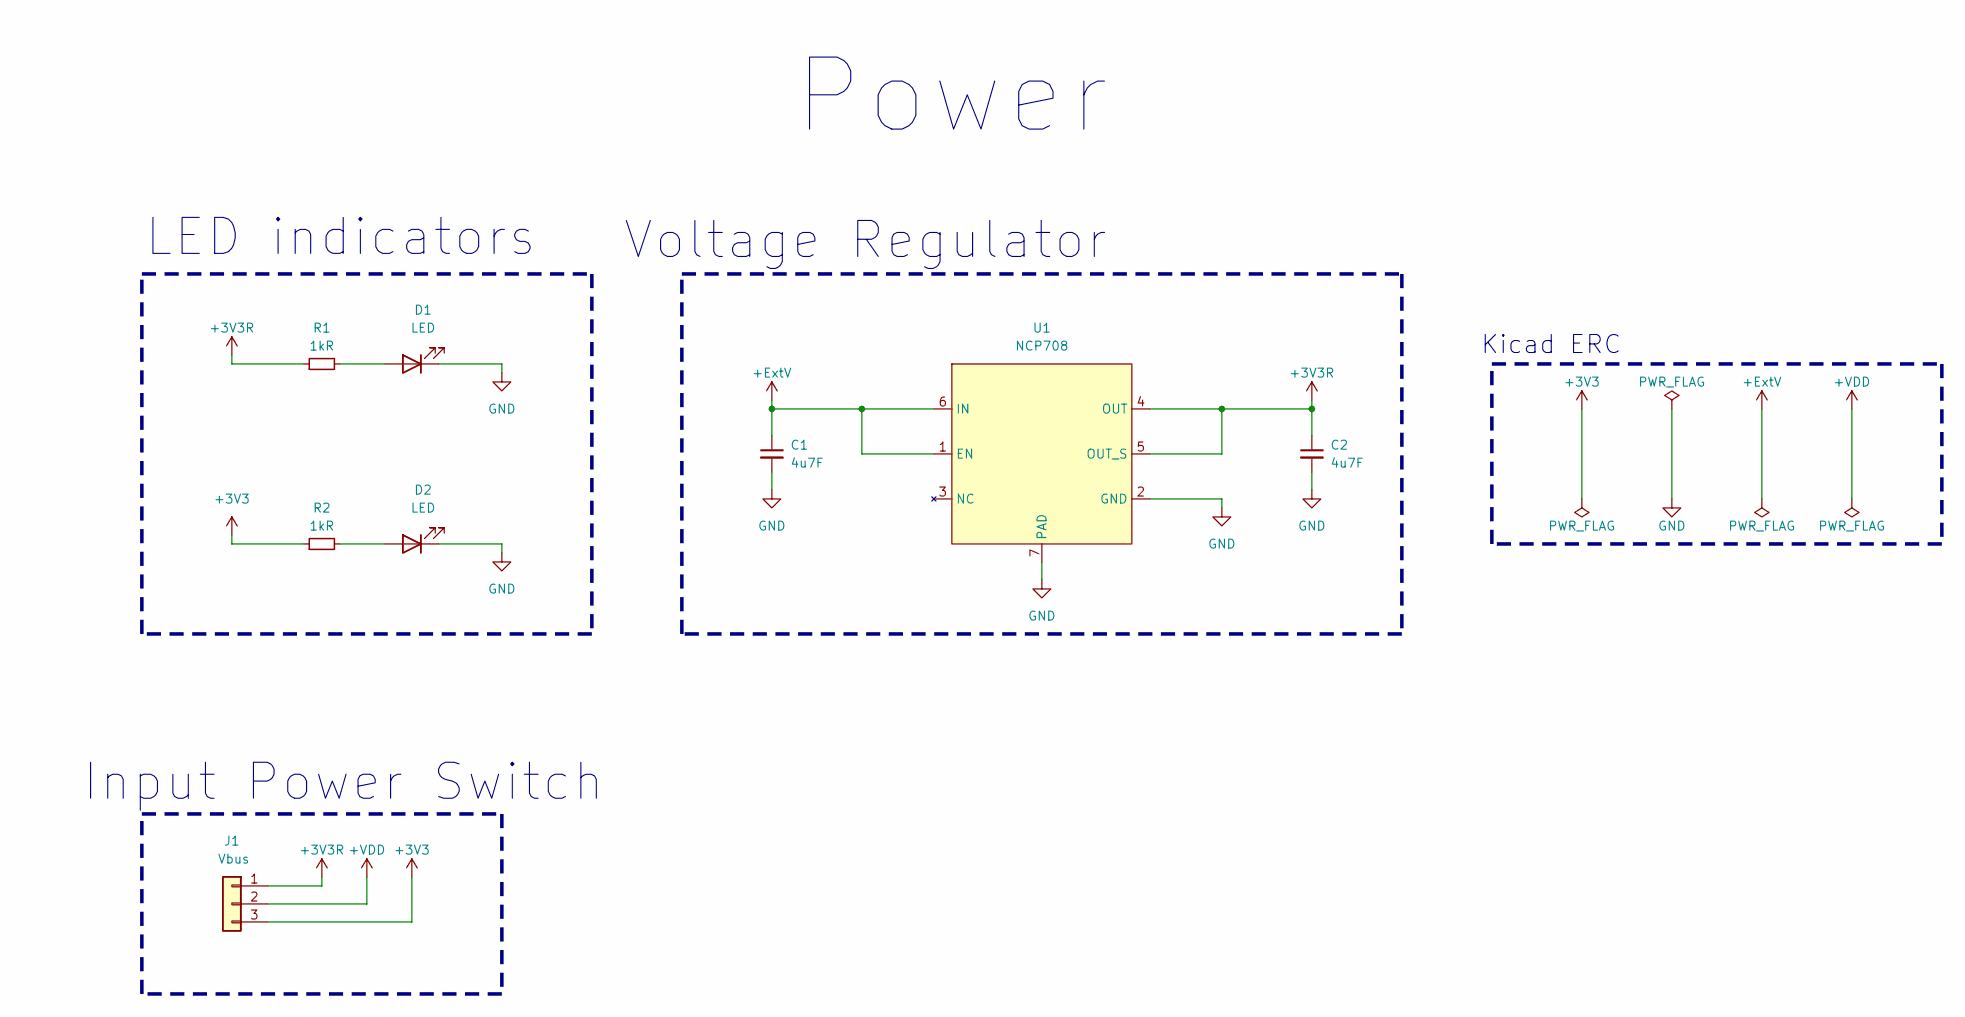
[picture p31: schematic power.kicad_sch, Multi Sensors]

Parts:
C1, C2: 4u7F; C_0402_1005Metric
D1, D2: LED; LED_0805_2012
J1: Vbus; PinHeader_1x03_P2.54mm_Vertical
R1, R2: 1kR; R_0402_1005Metric
U1: NCP708

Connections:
+3V3: J1.3, R2.1; also elsewhere on the board
+3V3R: C2.1, J1.1, R1.1, U1.4 (OUT), U1.5 (OUT_S)
+ExtV: C1.1, U1.1 (EN), U1.6 (IN); also elsewhere on the board
+VDD: J1.2; also elsewhere on the board
GND: C1.2, C2.2, D1.1 (K), D2.1 (K), U1.2 (GND), U1.7 (PAD); also elsewhere on the board
unnamed: D1.2 (A), R1.2
unnamed: D2.2 (A), R2.2

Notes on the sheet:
Power
LED indicators
Voltage Regulator
Input Power Switch
Kicad ERC

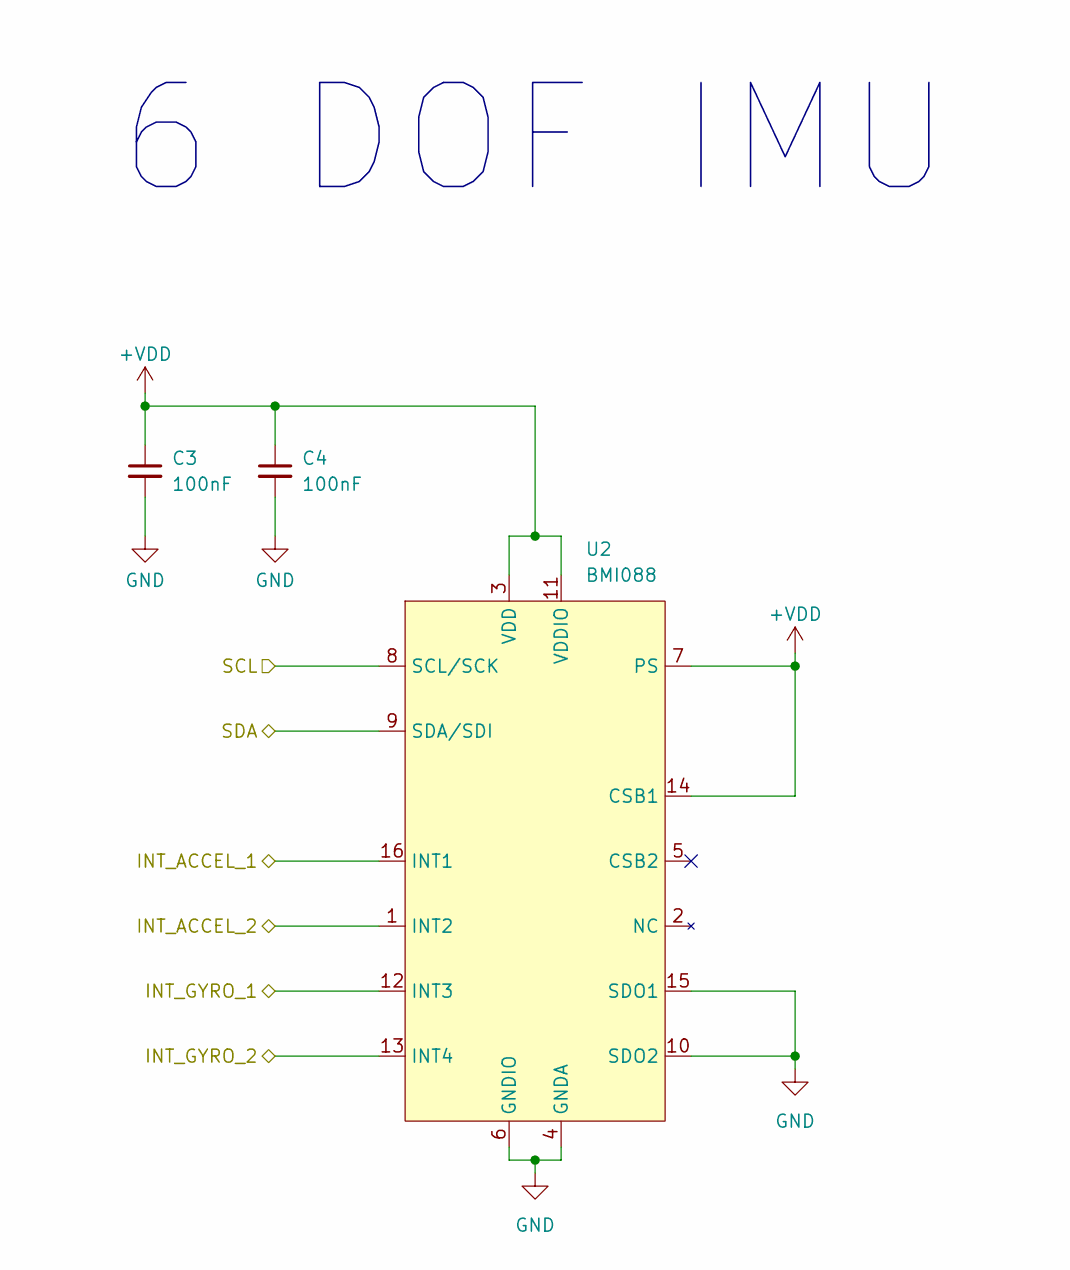
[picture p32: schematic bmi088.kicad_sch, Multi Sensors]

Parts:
C3, C4: 100nF; C_0402_1005Metric
U2: BMI088

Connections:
+VDD: C3.1, C4.1, U2.3 (VDD), U2.7 (PS), U2.11 (VDDIO), U2.14 (CSB1); also elsewhere on the board
/Block Diagram/BMI 088/INT_ACCEL_1: U2.16 (INT1); also elsewhere on the board
/Block Diagram/BMI 088/INT_ACCEL_2: U2.1 (INT2); also elsewhere on the board
/Block Diagram/BMI 088/INT_GYRO_1: U2.12 (INT3); also elsewhere on the board
/Block Diagram/BMI 088/INT_GYRO_2: U2.13 (INT4); also elsewhere on the board
/Block Diagram/SCL: U2.8 (SCL/SCK); also elsewhere on the board
/Block Diagram/SDA: U2.9 (SDA/SDI); also elsewhere on the board
GND: C3.2, C4.2, U2.4 (GNDA), U2.6 (GNDIO), U2.10 (SDO2), U2.15 (SDO1); also elsewhere on the board

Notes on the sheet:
6 DOF IMU

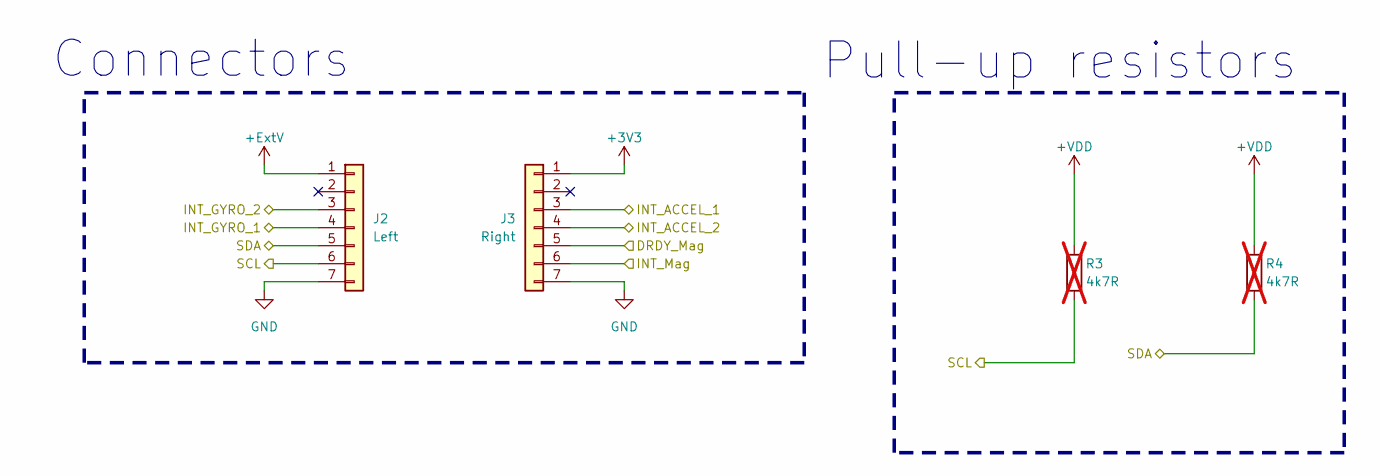
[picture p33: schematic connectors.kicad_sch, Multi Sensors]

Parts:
J2: Left; PinHeader_1x07_P2.54mm_Vertical
J3: Right; PinHeader_1x07_P2.54mm_Vertical
R3, R4: 4k7R; R_0402_1005Metric; not fitted

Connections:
+3V3: J3.1; also elsewhere on the board
+ExtV: J2.1; also elsewhere on the board
+VDD: R3.1, R4.1; also elsewhere on the board
/Block Diagram/BMI 088/INT_ACCEL_1: J3.3; also elsewhere on the board
/Block Diagram/BMI 088/INT_ACCEL_2: J3.4; also elsewhere on the board
/Block Diagram/BMI 088/INT_GYRO_1: J2.4; also elsewhere on the board
/Block Diagram/BMI 088/INT_GYRO_2: J2.3; also elsewhere on the board
/Block Diagram/BMM 150/DRDY_Mag: J3.5; also elsewhere on the board
/Block Diagram/BMM 150/INT_Mag: J3.6; also elsewhere on the board
/Block Diagram/SCL: J2.6, R3.2; also elsewhere on the board
/Block Diagram/SDA: J2.5, R4.2; also elsewhere on the board
GND: J2.7, J3.7; also elsewhere on the board

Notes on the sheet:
Connectors
Pull-up resistors

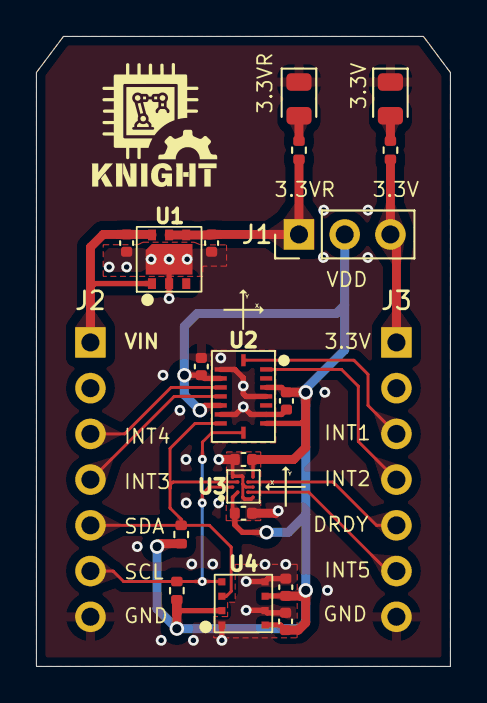
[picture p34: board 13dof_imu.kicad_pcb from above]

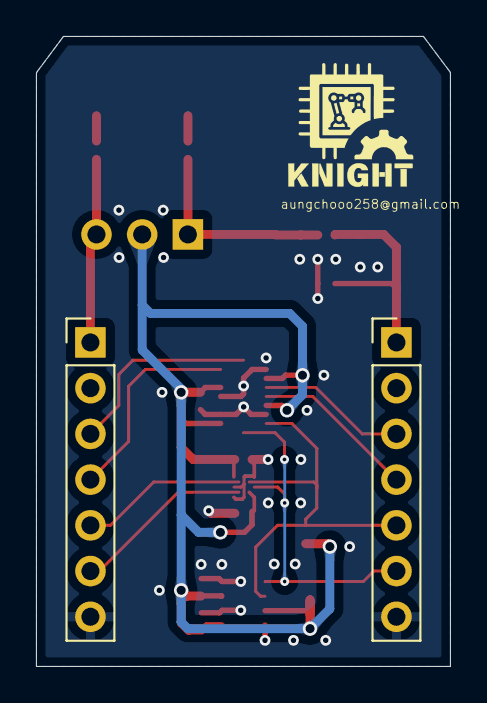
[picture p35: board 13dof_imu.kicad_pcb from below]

Board: 4 copper layers, 23.0 x 35.0 mm, 21 parts (2 on the bottom side), 15 nets.
